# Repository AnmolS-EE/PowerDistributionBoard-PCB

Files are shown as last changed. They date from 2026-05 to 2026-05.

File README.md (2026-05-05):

# PowerDistributionBoard-PCB
A high-efficiency power distribution board (PDB) designed to convert a single DC input (24V/10A) into multiple regulated rails for laboratory and personal device charging. This project has a custom-designed buck converter stage, individual USB Power Delivery (PD) controllers, and an ESP32 for real-time telemetry and monitoring. It will be designed on a 4-layer PCB board designed in KiCad.
## Schematic
V1.0 of the schematic is complete. As seen by the image below, it is neatly organized into the four main compartments: MCU(Microcontroller), Power management, Power analysis and USB ports.
V1.0 Schematic
## PCB Design
The PCB design and layout is currently a work in progress. Schematic and simulations are being thoroughly verified first. 

## Simulations
### 24V to 5V Step-Down Buck Converter
**Objective:** Step down the 24V main system power to a highly stable 5V rail.

**Simulation Note (XL4016 vs. LT1074):** 
The XL4016 used in the KiCad schematic doesn’t have a public SPICE model, so I used the Analog Devices LT1074 to simulate the circuit and verify the LC filter design and transient behavior.
 
 Note: The feedback resistors in the simulation (1kΩ / 1.26kΩ) were chosen to match the LT1074’s 2.21V reference. On the actual PCB, I’m using (1kΩ / 3kΩ) based on the XL4016’s 1.25V reference.

**Simulation & Stress Test:**
I tested the regulator under a continuous 2.5A load (modeled as 2Ω) to check how the 47µH inductor and 470µF output capacitors perform. The capacitors were modeled with a realistic ESR of 50mΩ.

**1. Transient Startup & Output Ripple:**
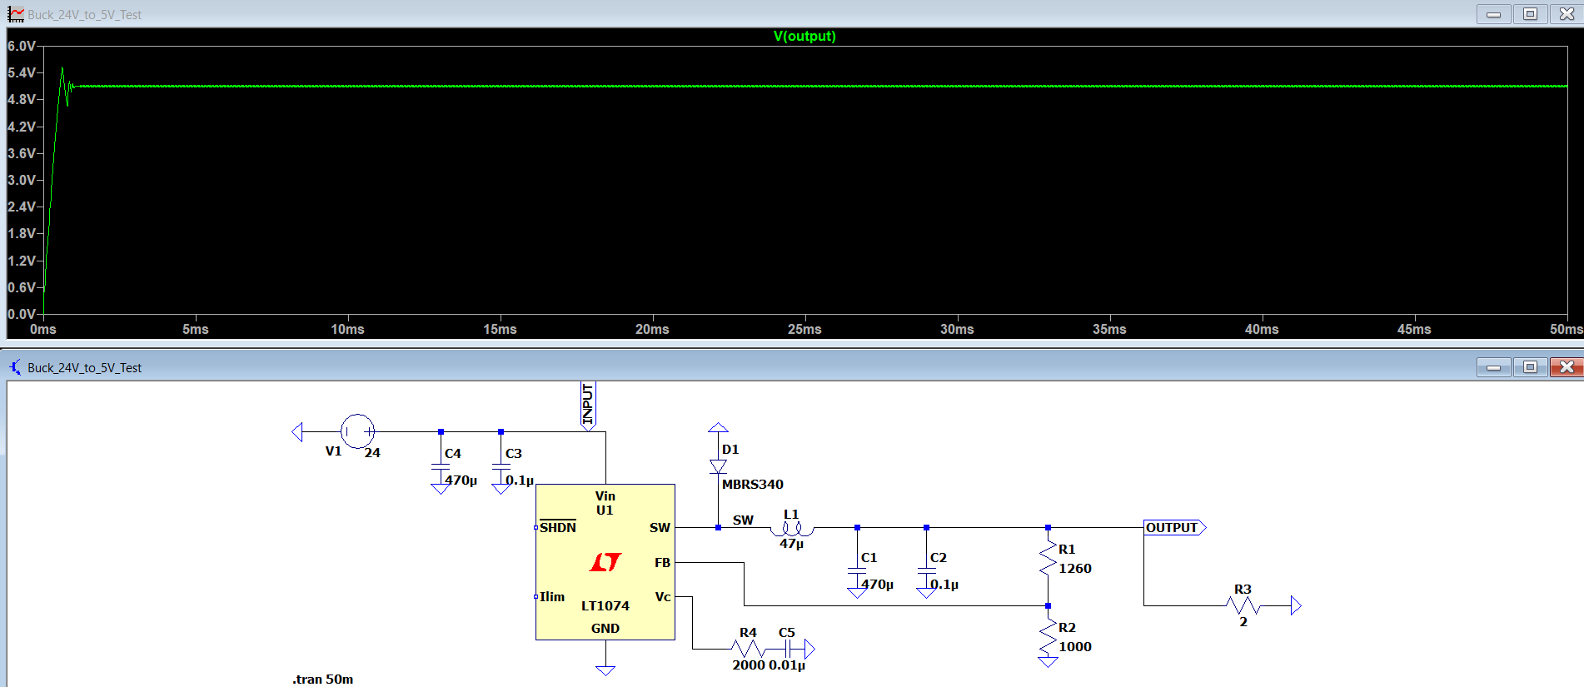
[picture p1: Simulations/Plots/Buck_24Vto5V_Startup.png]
5V Rail Startup

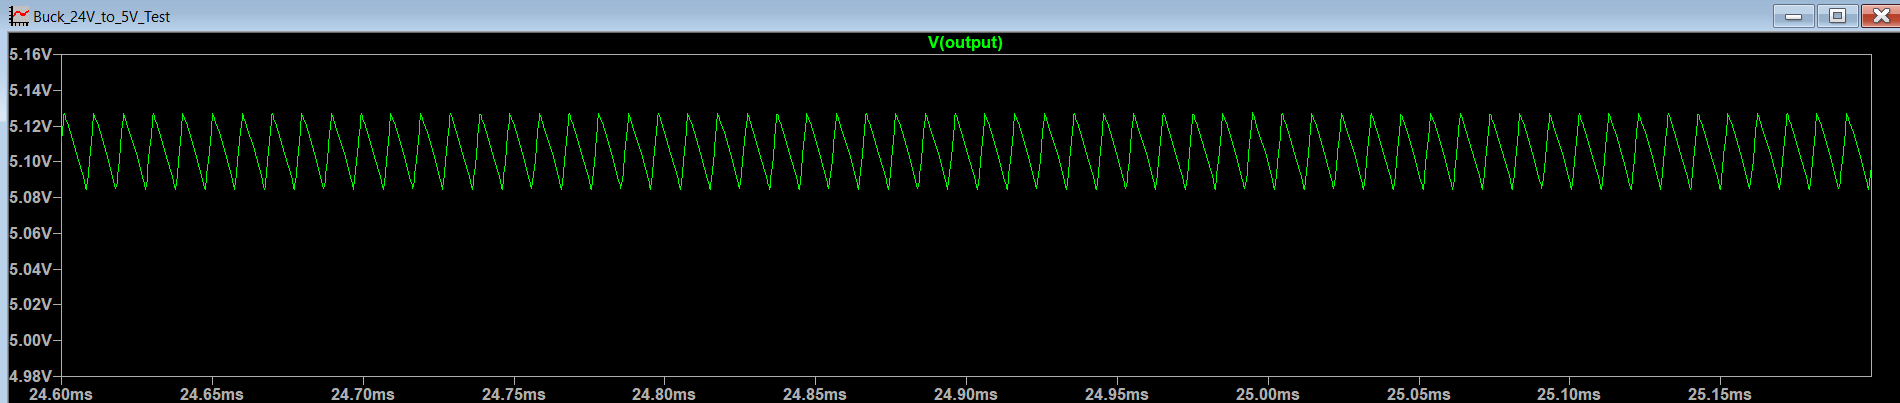
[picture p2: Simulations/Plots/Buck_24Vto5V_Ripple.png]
5V Rail Ripple


The system ramps up to 5V in less than 2ms. Steady-state analysis at full load shows a peak-to-peak voltage ripple of roughly 40mV (under 1%), confirming the power delivery is quite clean.

### 3.3V Logic Rail
**Objective:** Provide a stable power rail for the ESP32-S3-WROOM-1 microcontroller and I2C peripherals using the AMS1117-3.3. 

**Simulation & Stress Test:**
To verify the stability of the AMS1117-3.3V LDO regulator, the circuit was simulated in LTspice. I applied a 5-ohm load to force a continuous 660mA draw which is double the worst-case scenario in real life.

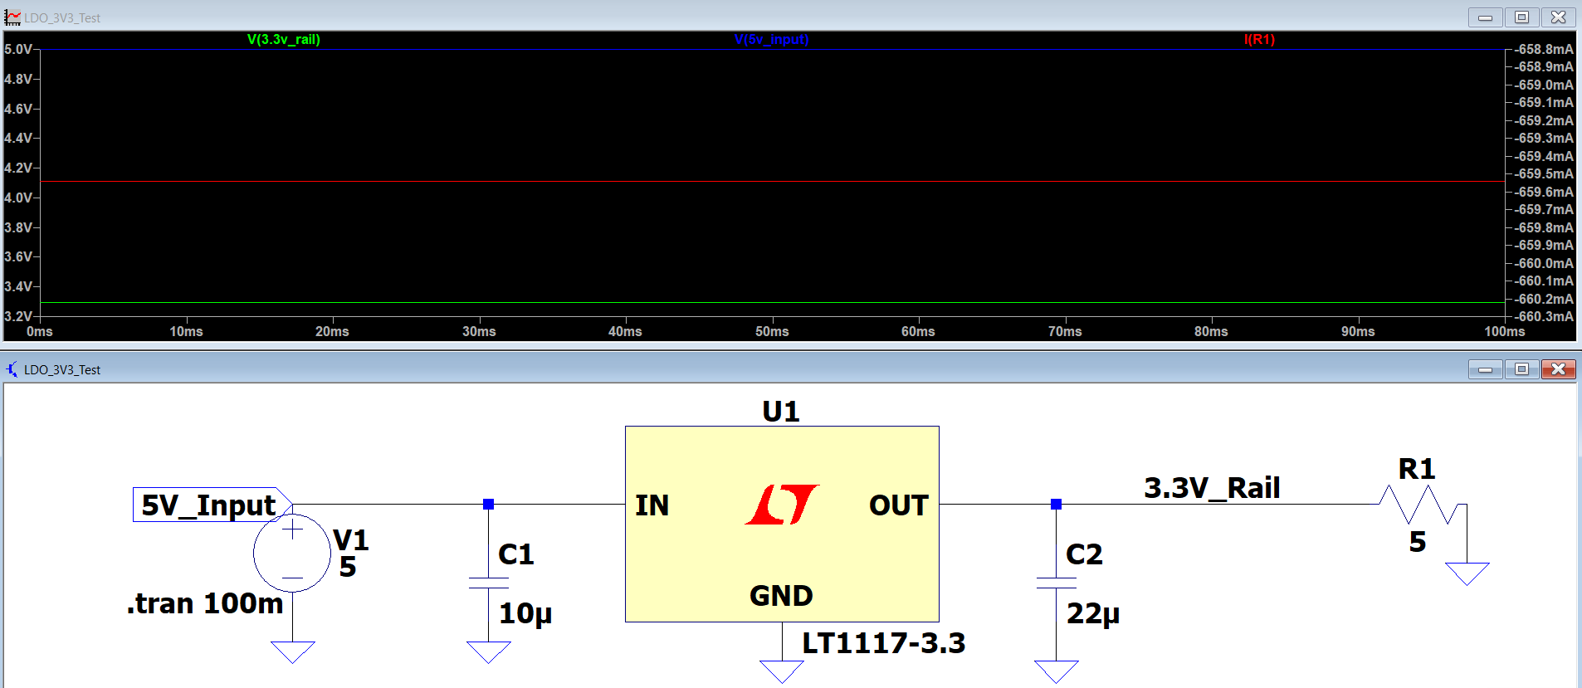
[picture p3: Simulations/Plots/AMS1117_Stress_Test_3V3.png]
LTspice Simulation: 3.3V Rail Schematic and Stress Test Graph


**Conclusion:**
As shown in the transient analysis above, the input of 5V (blue line) is converted into 3.3V (green line). The total load of the 3.3V rail (red line) remains perfectly flat under a 660mA continuous load with no voltage drop. The schematic confirms the test parameters, proving the power delivery is efficient enough to power the microcontroller and other perpherals.

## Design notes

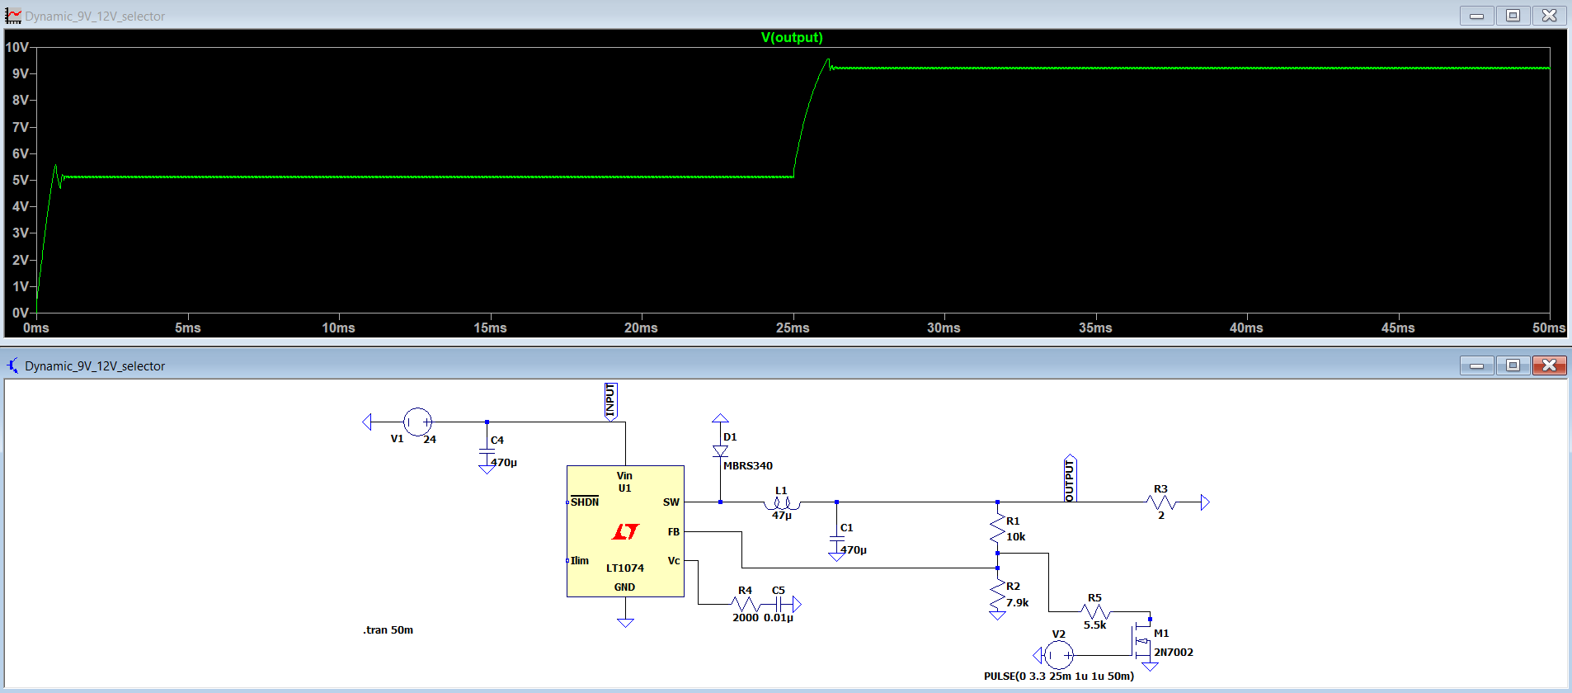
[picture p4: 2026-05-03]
Simulations/Plots/Dynamic_9V_12V_Selector.png

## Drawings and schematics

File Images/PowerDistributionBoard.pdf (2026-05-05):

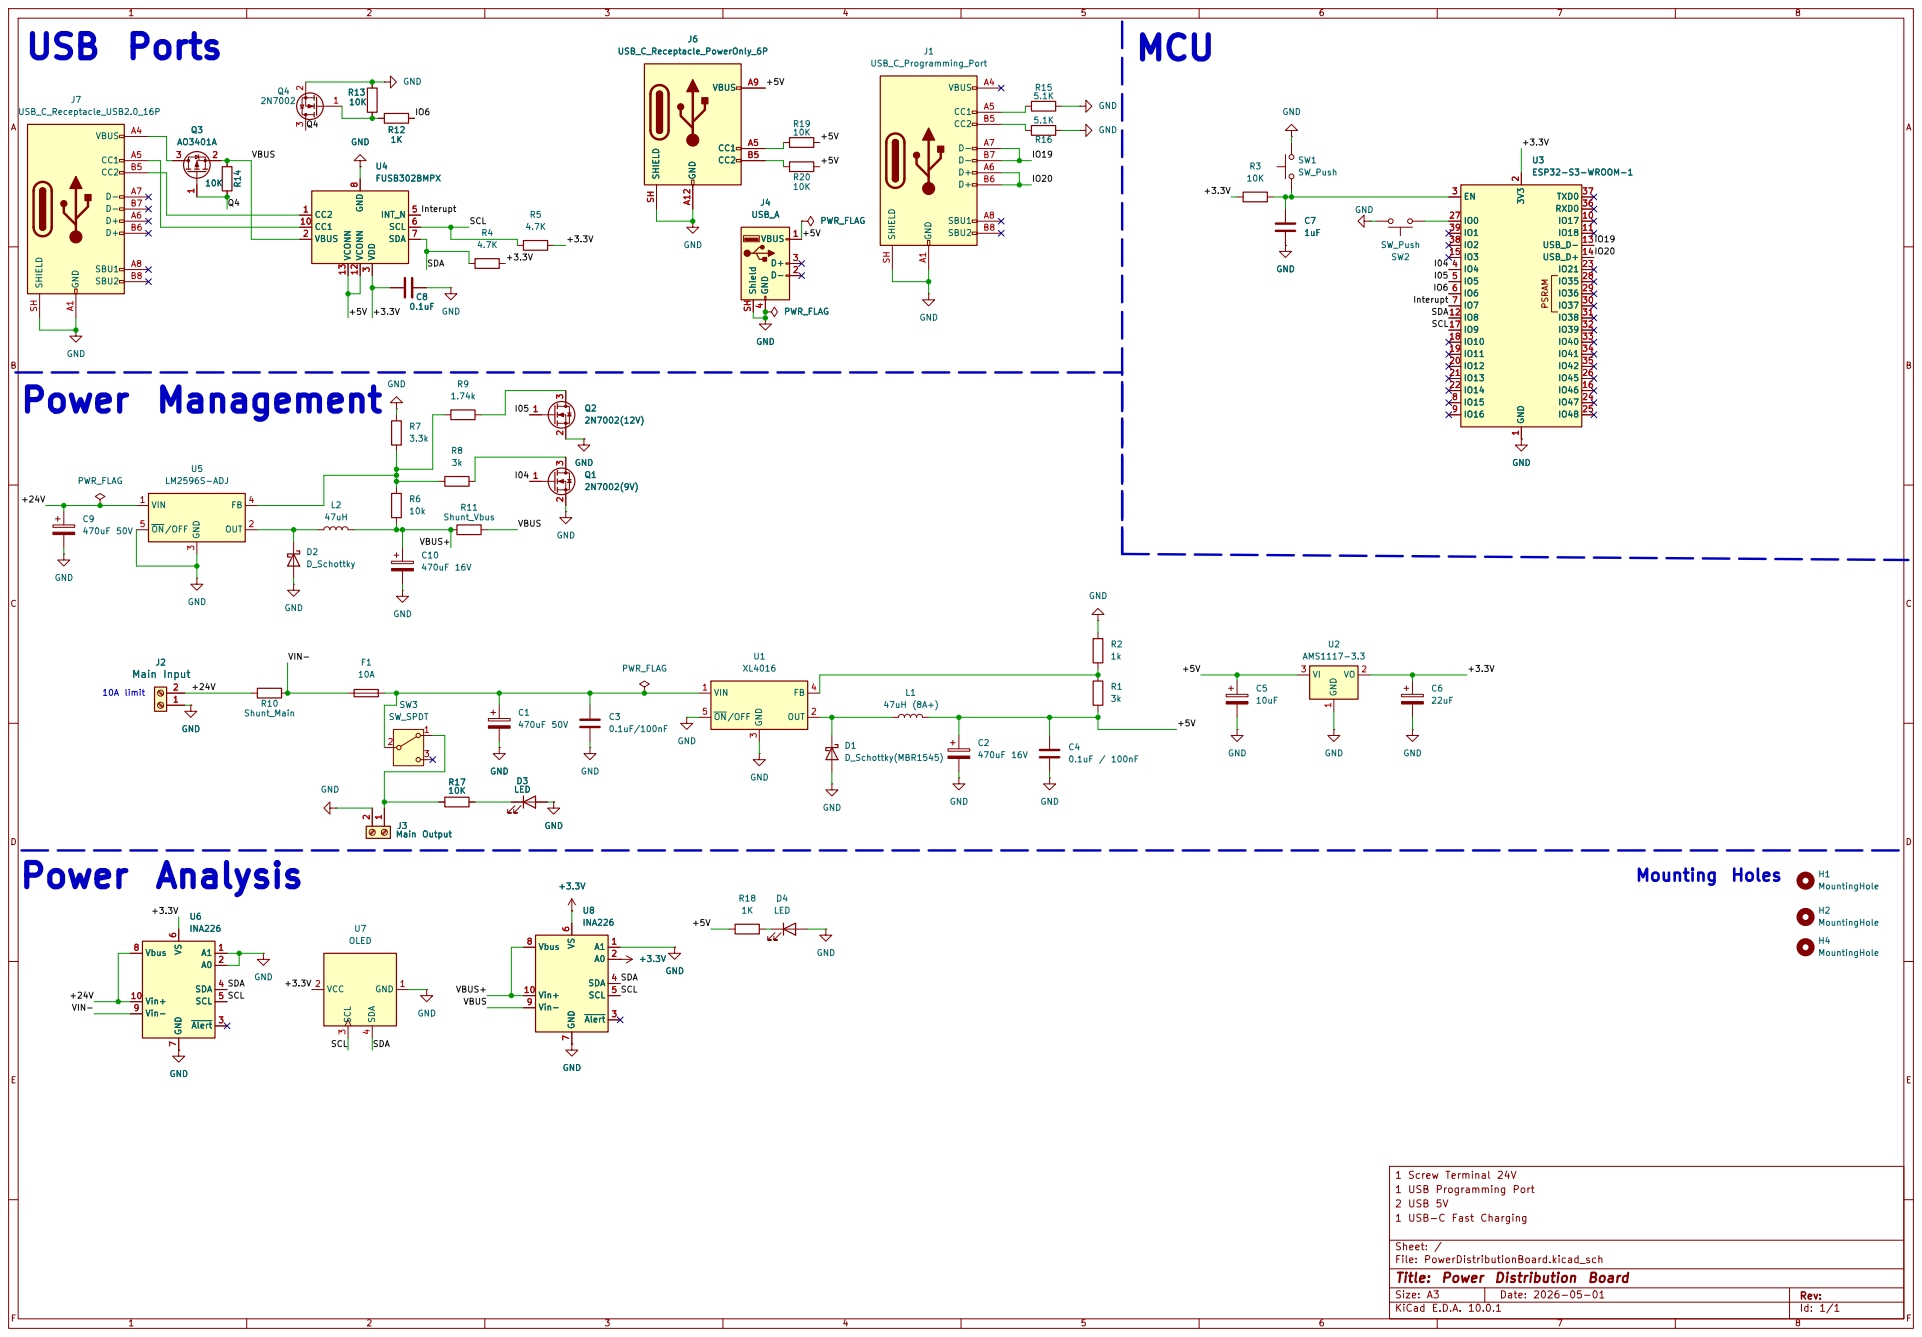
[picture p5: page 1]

Sheet: /
File: PowerDistributionBoard.kicad_sch
Title: Power Distribution Board

Size: A3 | Rev: | F Date: 2026-05-01
KiCad E.D.A. 10.0.1 | Id: 1/1

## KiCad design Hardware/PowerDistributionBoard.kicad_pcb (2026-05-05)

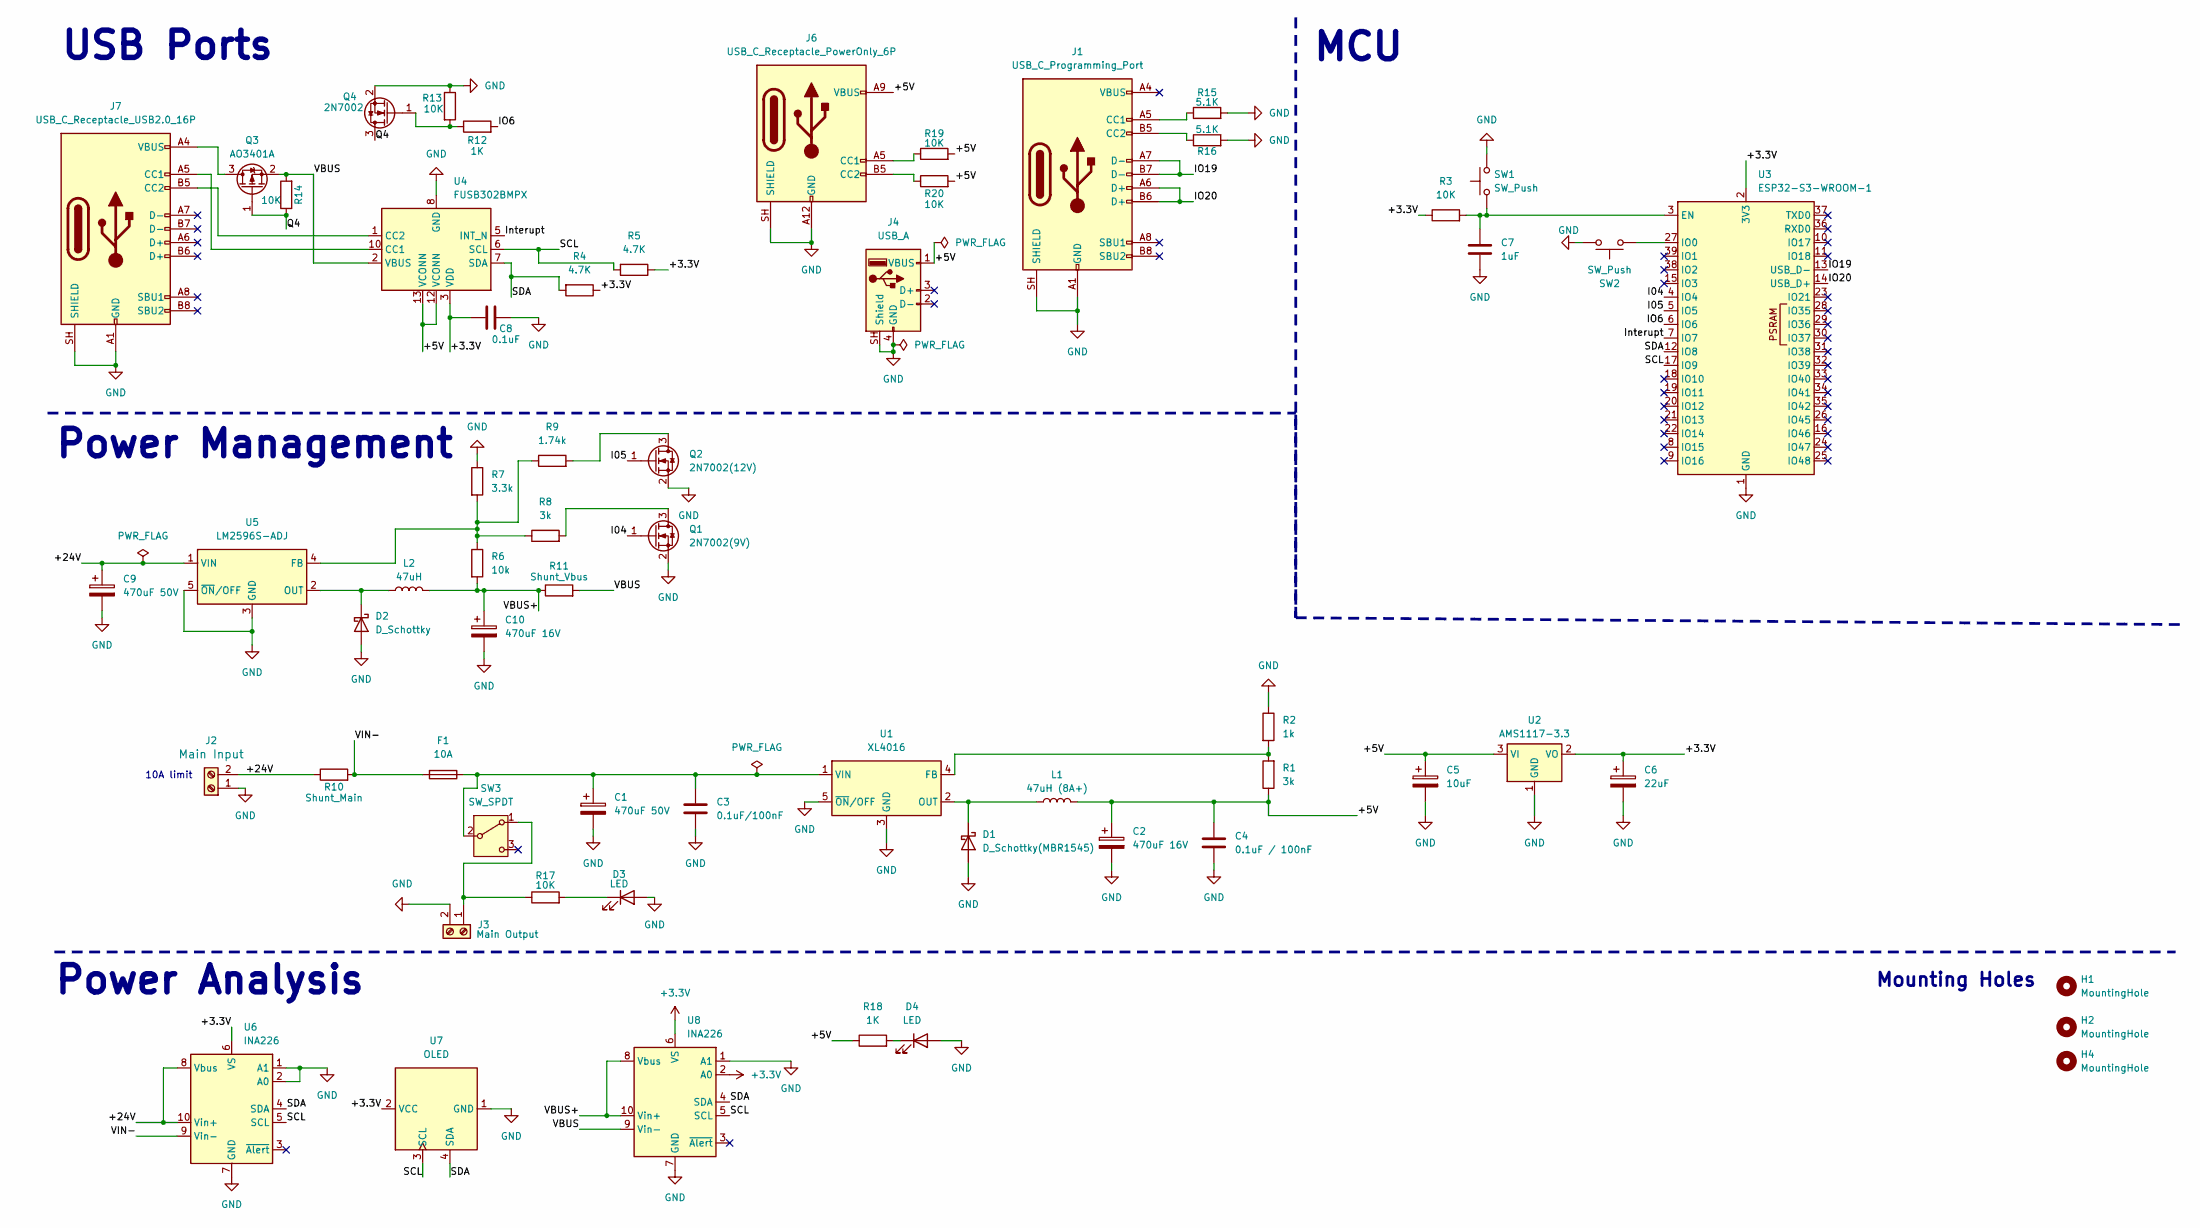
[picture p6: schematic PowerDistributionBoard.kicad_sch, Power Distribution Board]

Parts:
C1, C9: 470uF 50V; CP_Radial_D10.0mm_P5.00mm
C2, C10: 470uF 16V; CP_Radial_D8.0mm_P3.50mm
C3: 0.1uF/100nF; C_0805_2012Metric_Pad1.18x1.45mm_HandSolder
C4: 0.1uF / 100nF; C_0805_2012Metric_Pad1.18x1.45mm_HandSolder
C5: 10uF; CP_Radial_D5.0mm_P2.00mm
C6: 22uF; CP_Radial_D5.0mm_P2.00mm
C7: 1uF; C_0805_2012Metric_Pad1.18x1.45mm_HandSolder
C8: 0.1uF; C_0805_2012Metric_Pad1.18x1.45mm_HandSolder
D1: D_Schottky(MBR1545); TO-220-2_Vertical
D2: D_Schottky; D_SMC_Handsoldering
D3, D4: LED; LED_D3.0mm
F1: 10A; Fuseholder_Cylinder-5x20mm_Schurter_0031_8201_Horizontal_Op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
H1, H2, H4: MountingHole; MountingHole_3.2mm_M3
J1: USB_C_Programming_Port; USB_C_Receptacle_HRO_TYPE-C-31-M-12
J2: Main Input; TerminalBlock_Phoenix_MKDS-1,5-2-5.08_1x02_P5.08mm_Horizont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
J3: Main Output; TerminalBlock_Phoenix_MKDS-1,5-2-5.08_1x02_P5.08mm_Horizont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
J4: USB_A; USB_A_Molex_67643_Horizontal
J6: USB_C_Receptacle_PowerOnly_6P; USB_C_Receptacle_GCT_USB4125-xx-x_6P_TopMnt_Horizontal
J7: USB_C_Receptacle_USB2.0_16P; USB_C_Receptacle_HRO_TYPE-C-31-M-12
L1: 47uH (8A+); L_Toroid_Vertical_L24.6mm_W15.5mm_P11.44mm_Pulse_KM-4
L2: 47uH; L_12x12mm_H8mm
Q1: 2N7002(9V); SOT-23
Q2: 2N7002(12V); SOT-23
Q3: AO3401A; SOT-23
Q4: 2N7002; SOT-23
R1, R8: 3k; R_0805_2012Metric_Pad1.20x1.40mm_HandSolder
R2: 1k; R_0805_2012Metric_Pad1.20x1.40mm_HandSolder
R3, R13, R14, R17, R19, R20: 10K; R_0805_2012Metric_Pad1.20x1.40mm_HandSolder
R4, R5: 4.7K; R_0805_2012Metric_Pad1.20x1.40mm_HandSolder
R6: 10k; R_0805_2012Metric_Pad1.20x1.40mm_HandSolder
R7: 3.3k; R_0805_2012Metric_Pad1.20x1.40mm_HandSolder
R9: 1.74k; R_0805_2012Metric_Pad1.20x1.40mm_HandSolder
R10: Shunt_Main; R_2512_6332Metric_Pad1.40x3.35mm_HandSolder
R11: Shunt_Vbus; R_2512_6332Metric_Pad1.40x3.35mm_HandSolder
R12, R18: 1K; R_0805_2012Metric_Pad1.20x1.40mm_HandSolder
R15, R16: 5.1K; R_0805_2012Metric_Pad1.20x1.40mm_HandSolder
SW1, SW2: SW_Push; SW_PUSH_6x6mm_2Pin_P5.08mm
SW3: SW_SPDT; SW_Slide_SPDT_Straight_CK_OS102011MS2Q
U1: XL4016; TO-220-5_Vertical
U2: AMS1117-3.3; SOT-223-3_TabPin2
U3: ESP32-S3-WROOM-1
U4: FUSB302BMPX; WQFN-14-1EP_2.5x2.5mm_P0.5mm_EP1.45x1.45mm
U5: LM2596S-ADJ; TO-263-5_TabPin3
U6, U8: INA226; TSSOP-10_3x3mm_P0.5mm
U7: OLED; miniOLED

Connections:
+3.3V: C6.1, C8.1, R3.1, R4.1, R5.1, U2.2 (VO), U3.2 (3V3), U4.3 (VDD), U4.4 (VDD), U6.6 (VS), U7.2 (VCC), U8.2 (A0), U8.6 (VS)
/+5V: C2.1, C4.1, C5.1, J4.1 (VBUS), J6.A9 (VBUS), J6.B9 (VBUS), L1.2, R1.1, R18.1, R19.2, R20.2, U2.3 (VI), U4.12 (VCONN), U4.13 (VCONN)
/+24V: C9.1, J2.2, R10.1, U5.1 (VIN), U6.8 (Vbus), U6.10 (Vin+)
/I04: Q1.1 (G), U3.4 (IO4)
/I05: Q2.1 (G), U3.5 (IO5)
/IO6: R12.2, U3.6 (IO6)
/IO19: J1.A7 (D-), J1.B7 (D-), U3.13 (USB_D-)
/IO20: J1.A6 (D+), J1.B6 (D+), U3.14 (USB_D+)
/Interupt: U3.7 (IO7), U4.5 (INT_N)
/Q4: Q3.1 (G), Q4.3 (D), R14.1
/SCL: R5.2, U3.17 (IO9), U4.6 (SCL), U6.5 (SCL), U7.3 (SCL), U8.5 (SCL)
/SDA: R4.2, U3.12 (IO8), U4.7 (SDA), U6.4 (SDA), U7.4 (SDA), U8.4 (SDA)
/VBUS: Q3.2 (S), R11.2, R14.2, U4.2 (VBUS), U8.9 (Vin-)
/VBUS+: C10.1, L2.2, R6.2, R11.1, U8.8 (Vbus), U8.10 (Vin+)
/VIN-: F1.2, R10.2, U6.9 (Vin-)
GND: C1.2, C2.2, C3.2, C4.2, C5.2, C6.2, C7.2, C8.2, C9.2, C10.2, D1.2 (A), D2.2 (A), D3.2 (A), D4.2 (A), J1.A1 (GND), J1.A12 (GND), J1.B1 (GND), J1.B12 (GND), J1.SH (SHIELD), J2.1, J3.2, J4.4 (GND), J4.SH (Shield), J6.A12 (GND), J6.B12 (GND), J6.SH (SHIELD), J7.A1 (GND), J7.A12 (GND), J7.B1 (GND), J7.B12 (GND), J7.SH (SHIELD), Q1.2 (S), Q2.2 (S), Q4.2 (S), R2.1, R7.1, R13.1, R15.2, R16.2, SW1.2, SW2.2, U1.3 (GND), U1.5 (~ON/OFF), U2.1 (GND), U3.1 (GND), U3.40 (GND), U3.41 (GND), U4.8 (GND), U4.9 (GND), U4.15 (GND), U5.3 (GND), U5.5 (~ON/OFF), U6.1 (A1), U6.2 (A0), U6.7 (GND), U7.1 (GND), U8.1 (A1), U8.7 (GND)
unnamed: D1.1 (K), L1.1, U1.2 (OUT)
unnamed: D2.1 (K), L2.1, U5.2 (OUT)
unnamed: D3.1 (K), R17.2
unnamed: D4.1 (K), R18.2
unnamed: J1.A5 (CC1), R15.1
unnamed: J1.B5 (CC2), R16.1
unnamed: J3.1, R17.1, SW3.1 (A)
unnamed: J6.A5 (CC1), R19.1
unnamed: J6.B5 (CC2), R20.1
unnamed: J7.A5 (CC1), U4.10 (CC1), U4.11 (CC1)
unnamed: J7.B5 (CC2), U4.1 (CC2), U4.14 (CC2)
unnamed: Q1.3 (D), R8.2
unnamed: Q2.3 (D), R9.2
unnamed: J7.A4 (VBUS), J7.A9 (VBUS), J7.B4 (VBUS), J7.B9 (VBUS), Q3.3 (D)
unnamed: Q4.1 (G), R12.1, R13.2
unnamed: C1.1, C3.1, F1.1, SW3.2 (B), U1.1 (VIN)
unnamed: R1.2, R2.2, U1.4 (FB)
unnamed: C7.1, R3.2, SW1.1, U3.3 (EN)
unnamed: SW2.1, U3.27 (IO0)
unnamed: R6.1, R7.2, R8.1, R9.1, U5.4 (FB)

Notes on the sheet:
Mounting Holes
MCU
USB Ports
Power Management
Power Analysis
10A limit

Board: 4 copper layers, 61 parts (0 on the bottom side), 36 nets, no tracks yet.

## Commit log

2026-04-30 Create .gitignore for KiCad project
    Add .gitignore for KiCad project files and temporary files.
2026-04-30 Inital KiCad files upload
    [PowerDistributionBoard.kicad_pcb, PowerDistributionBoard.kicad_sch]
2026-05-01 Upgraded the schematic
    [PowerDistributionBoard.kicad_sch]
2026-05-01 Updated Schematic
    [PowerDistributionBoard.kicad_sch]
2026-05-02 V1.0 of Schematic is complete
    [PowerDistributionBoard.kicad_sch]
2026-05-02 V1.0 of Schematic is complete.
    [PowerDistributionBoard.kicad_pcb, PowerDistributionBoard.kicad_sch]
2026-05-05 Uploading V1.0 Schematic pdf
    [PowerDistributionBoard.kicad_pcb, PowerDistributionBoard.kicad_sch]
2026-05-05 Expand README with project details and simulations
    Added detailed sections on schematic, PCB design, and simulations for the power distribution board project.
